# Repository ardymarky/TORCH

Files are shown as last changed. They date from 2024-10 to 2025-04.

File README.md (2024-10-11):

# TORCH
Code and Solidworks

To clone github, go to a folder or directory of your choice and run 
'git clone https://github.com/ardymarky/TORCH.git Torch`

To push you changes to the github, run these commands in order:

`git pull`
`git status` (make sure everything looks good)
`git add . ` (adds your changes)
`git commit -m "your message here"` (bundles them to a commit with a message)
`git push`  (push your changes to the main github branch!)

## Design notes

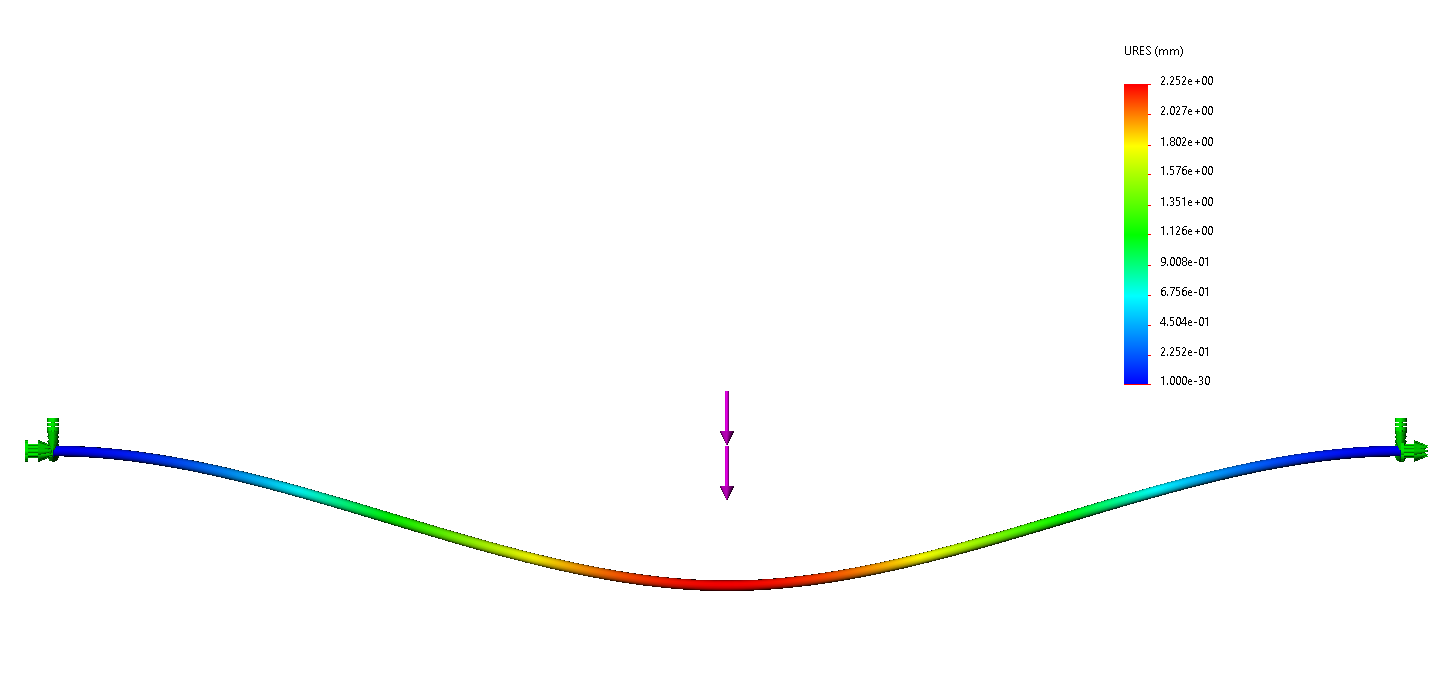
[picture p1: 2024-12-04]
6061_Aluminum_Alloy_Max_Deflection.png

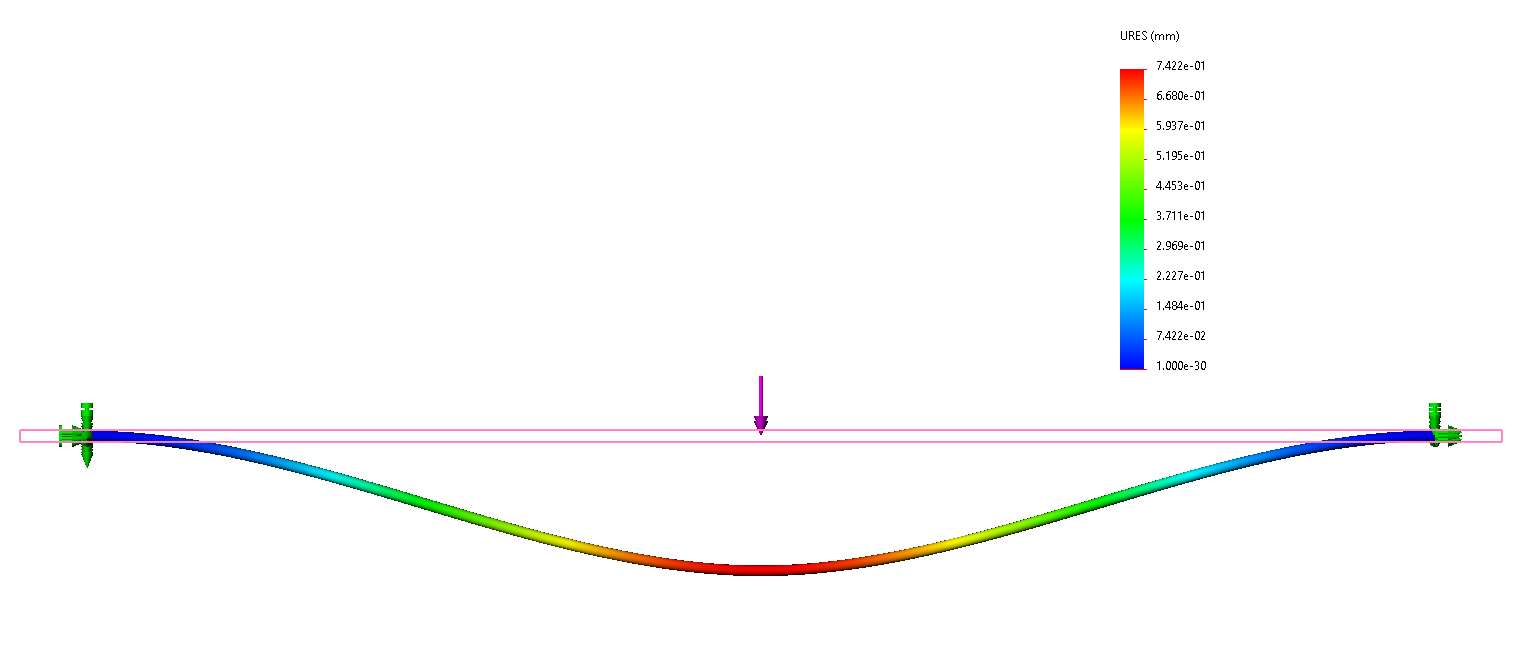
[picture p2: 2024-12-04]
Carbon_Steel_Max_Deflection.png

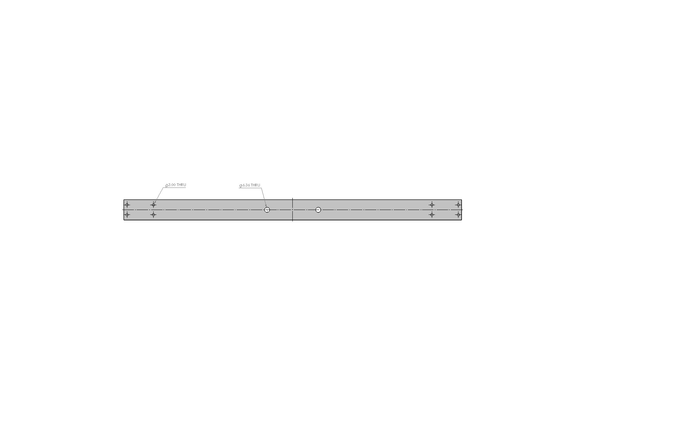
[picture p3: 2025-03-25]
solidworks/1630T291_Multipurpose 6061 Aluminum U-Channel_hole_cuts.JPG

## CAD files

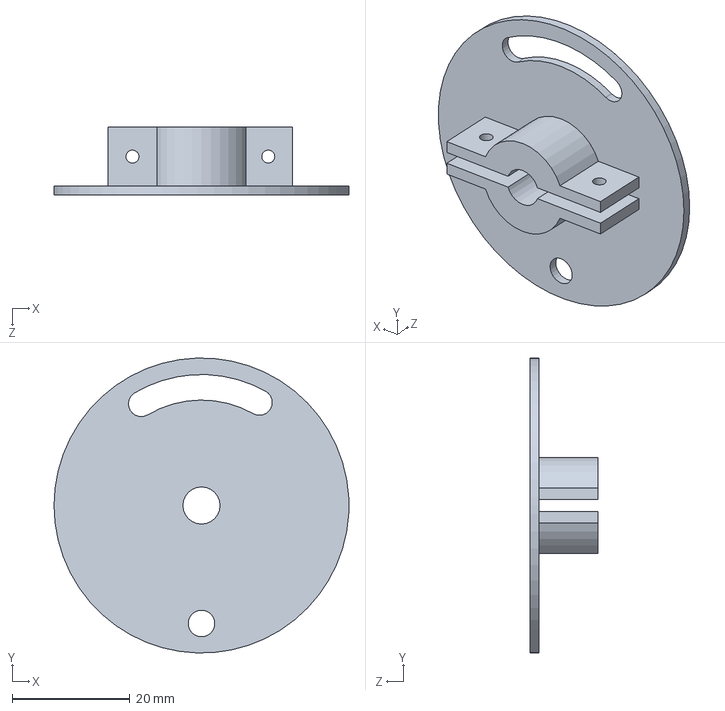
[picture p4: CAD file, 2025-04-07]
solidworks/WheelKey.SLDPRT
50.0 x 50.0 x 11.5 mm

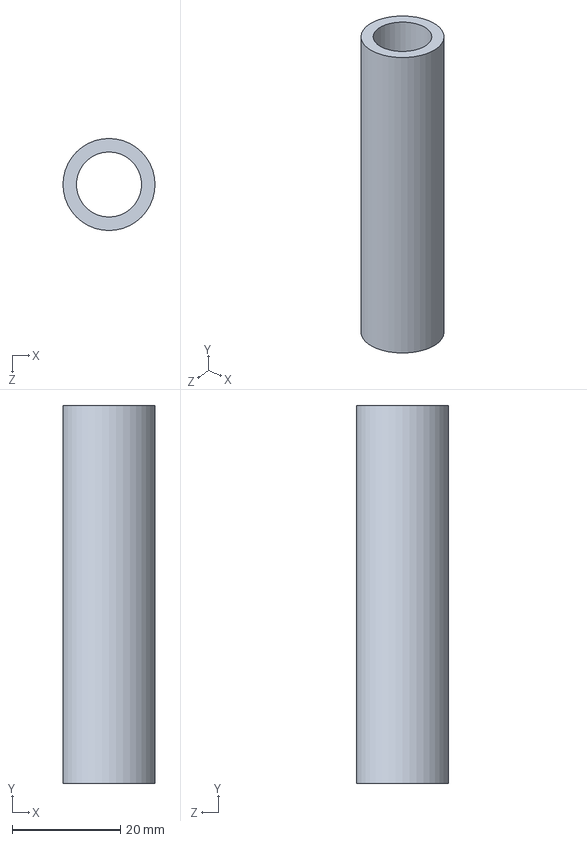
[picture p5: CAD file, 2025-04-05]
solidworks/rubberextrusion.SLDPRT
17.0 x 70.0 x 17.0 mm

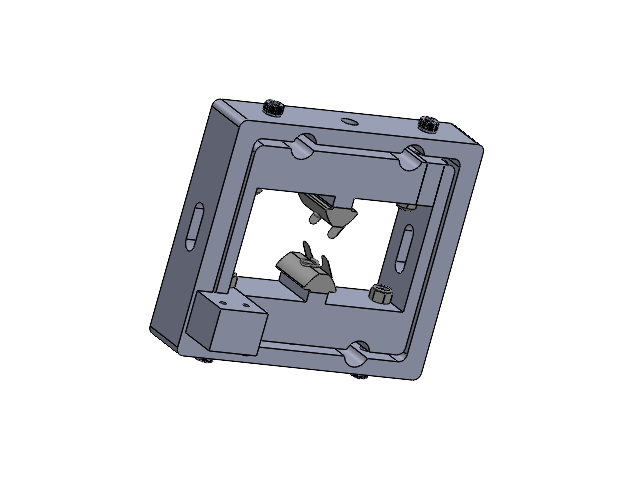
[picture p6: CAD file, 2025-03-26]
solidworks/Linear_rail_hold_V4_8.SLDASM
Linear_rail_hold_V4_2_new
Linear_rail_hold_V4_new
Linear_rail_hold_V4
91290A172_Alloy Steel Socket Head Screw x 4
5278N23_T-Slotted Framing Fasteners x 2
94645A101_High-Strength Steel Nylon-Insert Locknut x 4

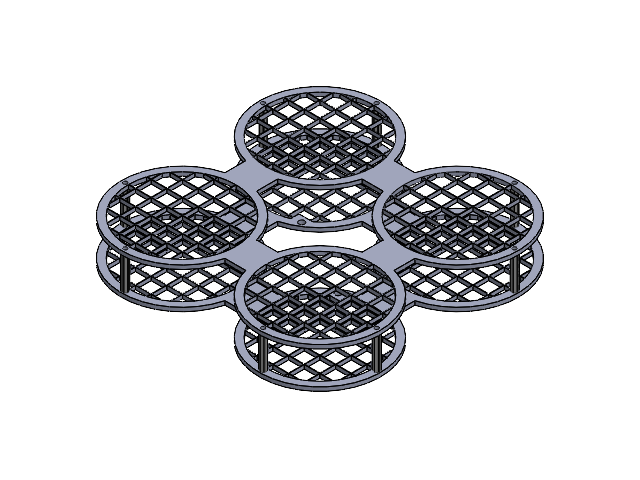
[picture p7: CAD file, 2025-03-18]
solidworks/drone_guard_combo.SLDASM
guard_bottom1_combo
93655A360_Male-Female Threaded Hex Standoff x 8
guard_combo

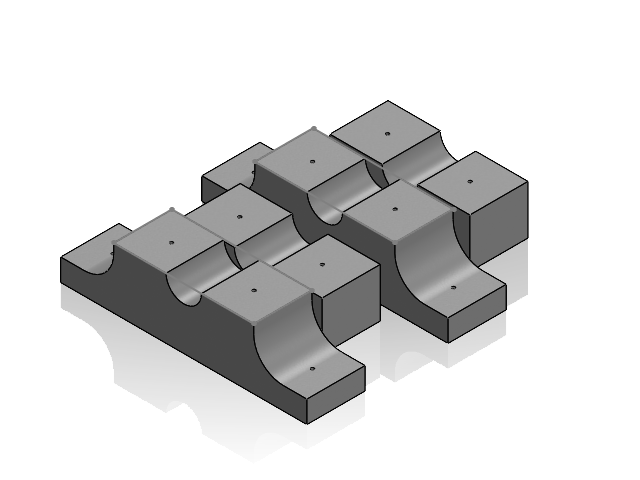
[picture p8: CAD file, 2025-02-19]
solidworks/clampPrint.SLDASM
clampBottomPrint x 2
clampTopPrint x 2

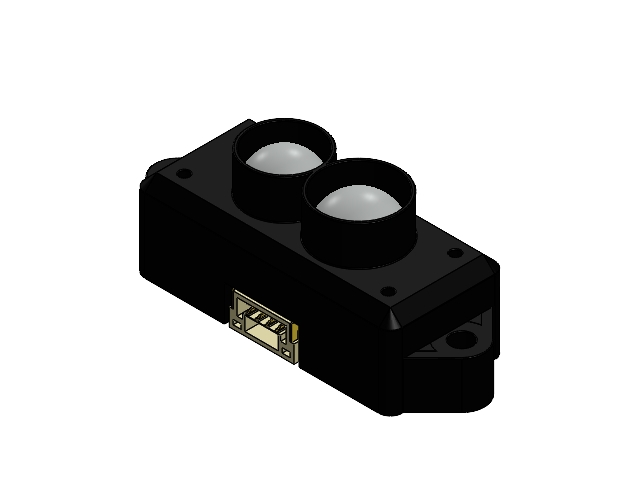
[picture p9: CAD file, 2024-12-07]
solidworks/LiDAR Benewake TFMini.SLDASM
LiDAR Benewake TFMini_1.stp
Lente Grande.stp
Lente Pequena.stp
SM04B-GHS-TB.stp
Chipset.stp
Adesivo.stp

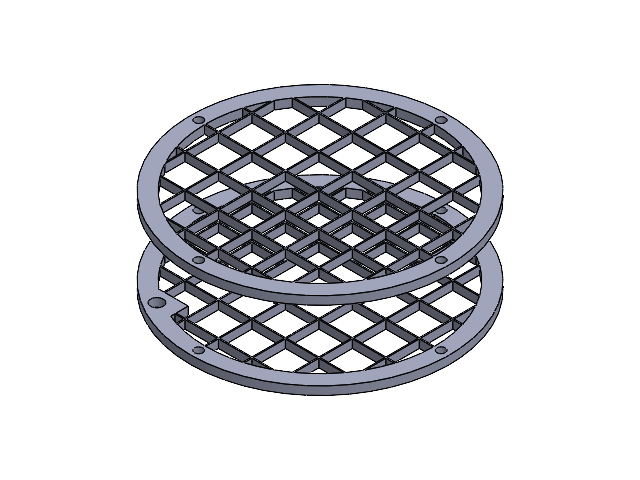
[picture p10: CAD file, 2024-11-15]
solidworks/one quard.SLDASM
guard
guard_bottom1

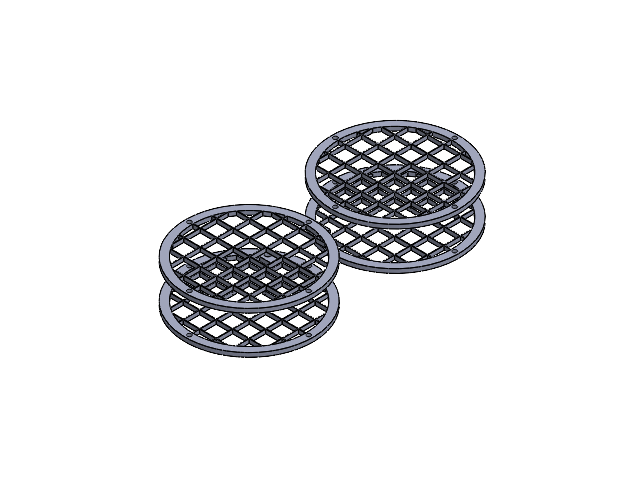
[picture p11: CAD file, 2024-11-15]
solidworks/half prop.SLDASM
guard x 2
guard_bottom1 x 2

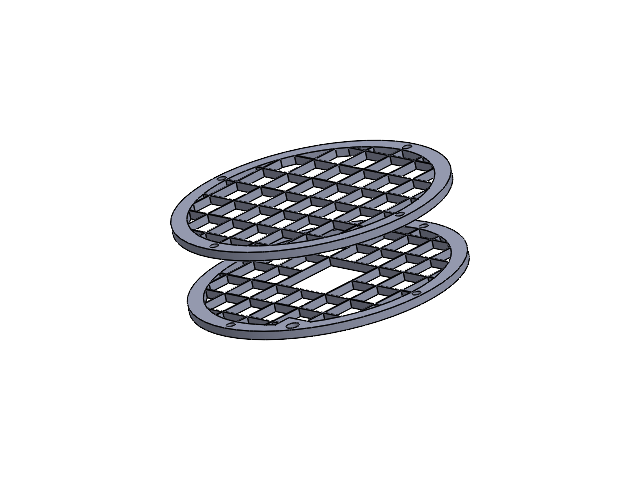
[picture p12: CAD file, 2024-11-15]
solidworks/one quard_1.SLDASM
guard
guard_bottom1

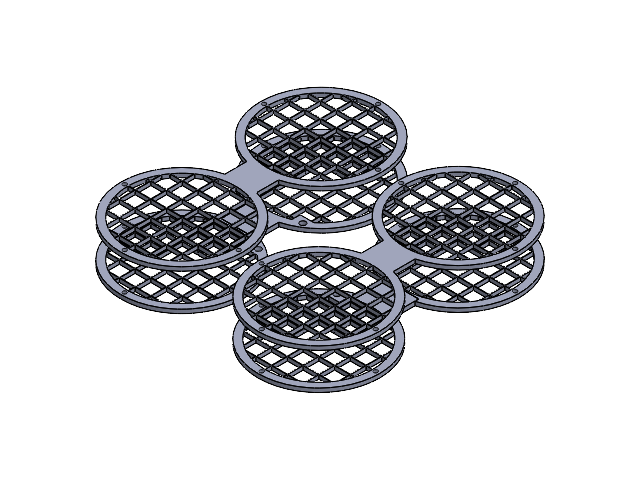
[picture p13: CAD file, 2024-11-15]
solidworks/experiment.SLDASM
half prop_COMBOpart x 2

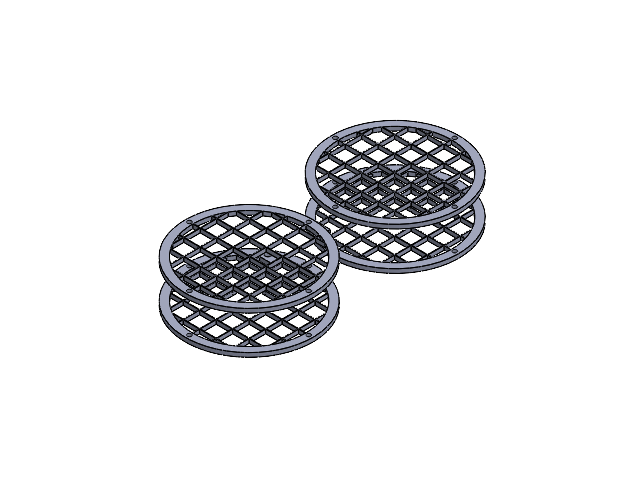
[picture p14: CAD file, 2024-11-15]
solidworks/half prop_COMBO.SLDASM
guard x 2
guard_bottom1 x 2

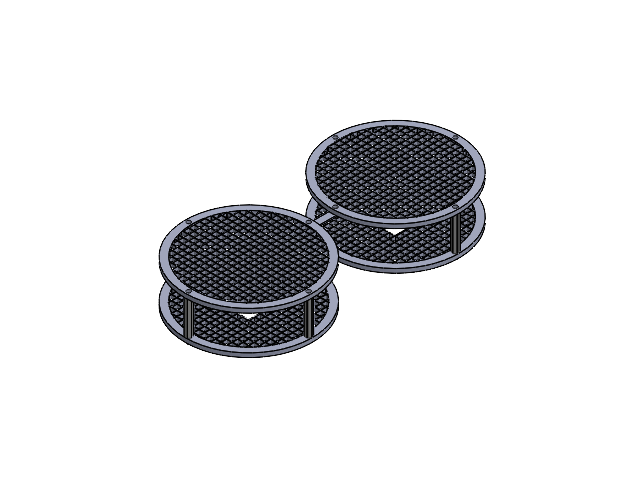
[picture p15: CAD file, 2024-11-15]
solidworks/half prop_one.SLDASM
guard x 2
93655A360_Male-Female Threaded Hex Standoff (1) x 6
guard_bottom1 x 2
connector x 2

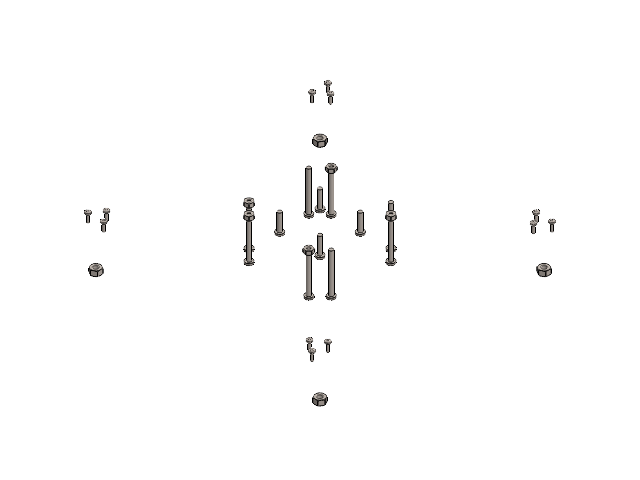
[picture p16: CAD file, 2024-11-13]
solidworks/final assembly.SLDASM
pan cross head_am x 24
hex nut style 2_am x 9

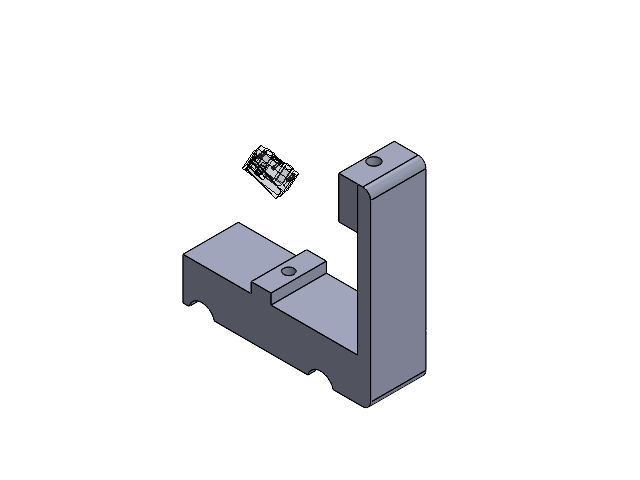
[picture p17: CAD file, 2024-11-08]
solidworks/Assem1.SLDASM
Linear_rail_hold_V4
Bottom.STEP
Top.STEP
Pins.STEP x 3
Button.STEP
Lever.STEP

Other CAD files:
solidworks/innerrail.SLDASM
solidworks/Linear_rail_hold_V4_3.SLDPRT.SLDASM
solidworks/E-Stop With Housing.SLDASM
solidworks/1630T116_Multipurpose 6061 Aluminum U-Channel.SLDPRT
solidworks/1630T291_Multipurpose 6061 Aluminum U-Channel Counterweight rack.SLDPRT
solidworks/1630T291_Multipurpose 6061 Aluminum U-Channel.SLDPRT
solidworks/1630T291_Multipurpose 6061 Aluminum U-Channel_hole_cuts.DWG
solidworks/1630T291_Multipurpose 6061 Aluminum U-Channel_hole_cuts.SLDDRW
solidworks/1630T332_Multipurpose 6061 Aluminum U-Channel.SLDPRT
solidworks/1865K36_Aluminum Easy-Access Base-Mounted Shaft Support.SLDPRT
solidworks/1865K36_Aluminum Easy-Access Base-Mounted Shaft Support1.SLDPRT
solidworks/2435K1_Idler Rotary Shaft.SLDPRT
solidworks/3014T45_Steel Eyebolt with Shoulder - for Lifting (1).SLDPRT
solidworks/3018T14_Galvanized Steel Eyebolt with Nut and with Shoulder (1).SLDPRT
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

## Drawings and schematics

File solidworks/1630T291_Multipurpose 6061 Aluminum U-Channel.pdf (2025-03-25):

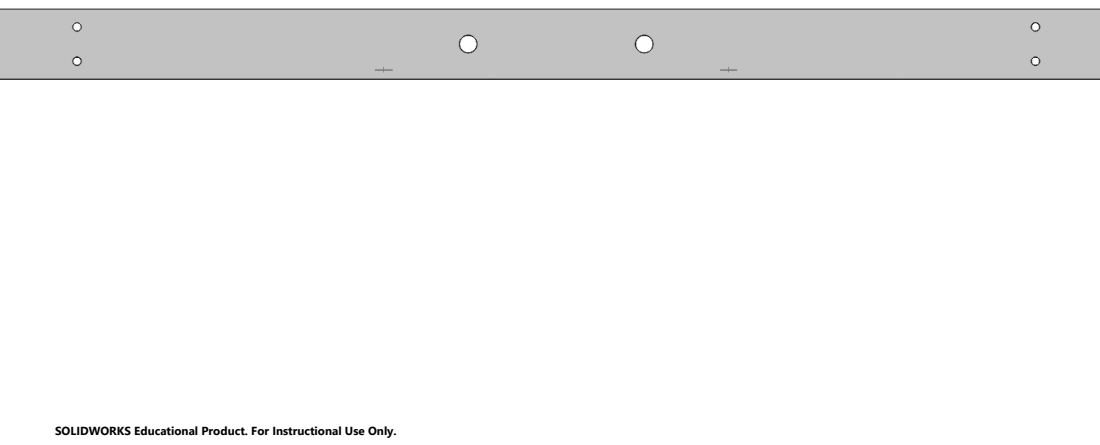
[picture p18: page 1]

SOLIDWORKS Educational Product. For Instructional Use Only.

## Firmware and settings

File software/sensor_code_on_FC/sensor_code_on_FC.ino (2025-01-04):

typedef union WheelReading{
  float angle_uart;
  byte byteArray[4]; /* you can use other variable types if you want. Like: a 32bit integer if you have 4 8bit variables in your struct */
};

uint8_t WE_state = 0;
WheelReading wheel_reading;

void setup() {
  Serial.begin(9600);
  Serial2.begin(9600);
  Serial3.begin(115200);
}

void loop() {
  if (Serial2.available()) {
    readWE_data();
  }
  if (Serial3.available()) {
    readRF_data();
  }
}

void readWE_data() {

    uint8_t WE_state = 0;
    uint8_t byte_num = 0;

    while (1) {

      if (Serial2.available()) {

        uint8_t val_1 = Serial2.read();

        if (WE_state == 2 && byte_num < 4) {
          wheel_reading.byteArray[byte_num] = val_1;
          byte_num += 1;
        }
        else if (WE_state == 2 && byte_num >= 4) {
          WE_state = 0;
          byte_num = 0;
          break;
        }
        else if (val_1 == 0x69 && WE_state == 0) {
          WE_state = 1;
          
        }
        else if (val_1 == 0x69 && WE_state == 1) {
          WE_state = 2;
        }
        else {
          WE_state = 0;
        }      
      }
    }

    unsigned long curMillis = millis();
    // Serial.print("Wheel reading: "); 
    Serial.print(wheel_reading.angle_uart);
    Serial.print("\t");
    Serial.println(curMillis);
}


void readRF_data() {
  int frame_size = 7;

    uint8_t frame[frame_size];
    uint8_t lastChar = 0x00; 

    while (1) {

      if (Serial3.available()) {      
        uint8_t curChar = Serial3.read();

        if ((lastChar == 0x59) && (curChar == 0x59)) {
          // Break to begin frame
          break;
          
        } else {
          // We have not seen two 0x59's in a row -- store the current character and continue reading.         
          lastChar = curChar;
        }           
      }
    }

    uint8_t checksum = 0x59 + 0x59;
    for (int i=0; i<frame_size; i++) {
      // Read one character
      while (!Serial3.available()) {
        // wait for a character to become available
      }    
      frame[i] = Serial3.read();

      // Store running checksum
      if (i < frame_size-2) {
        checksum += frame[i];
      }
    }

    // Step 3: Interpret frame
    uint16_t dist = (frame[1] << 8) + frame[0];
    uint16_t st = (frame[3] << 8) + frame[2];
    uint8_t reserved = frame[4];
    uint8_t originalSignalQuality = frame[5];


    // Step 4: Store values
    int distance = dist;
    int strength = st;

    unsigned long curMillis = millis();
    Serial.print("Rangfinder:");
    Serial.print("\t");
    Serial.print(distance);
    Serial.print(" cm\t");
    // Serial.print(strength);
    // Serial.print("\t");
    Serial.println(curMillis);
}

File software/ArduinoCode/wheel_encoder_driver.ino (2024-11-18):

#include "SPI.h"

#include "MLX90316.h"

/* MLX90316 Rotary Position Sensor */
byte pinSS = 3;
byte pinSCK = 4;
byte pinMOSI = 5;
// float rough_gain= 0x8;
float angle;

//Metro mlxMetro = Metro(5); 
MLX90316 mlx_1 = MLX90316(); 

void setup(){
  Serial.begin(9600); 
  mlx_1.attach(pinSS,pinSCK,pinMOSI); 
  SPI.begin();
  // Serial.println("MLX90316 Rotary Position Sensor");
}

void loop() {
  
    angle = mlx_1.readAngle();
    // float rough_gain = SPI.transfer(0x8);
    // Serial.print("angle = ");Serial.println((float)angle/10);

    typedef union WheelReading{
      float angle_uart;
      byte byteArray[4]; /* you can use other variable types if you want. Like: a 32bit integer if you have 4 8bit variables in your struct */
    };

    WheelReading wheel_reading;

    wheel_reading.angle_uart = (float)angle/10;

    Serial.write(0x69);
    Serial.write(0x69);
    Serial.write(wheel_reading.byteArray[0]);
    Serial.write(wheel_reading.byteArray[1]);
    Serial.write(wheel_reading.byteArray[2]);
    Serial.write(wheel_reading.byteArray[3]);

    }
  

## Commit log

2024-10-11 solidworks files
    [1865K36_Aluminum Easy-Access Base-Mounted Shaft Support.SLDPRT, 2435K1_Idler Rotary Shaft.SLDPRT, 4063N11_Base-Mounted Dual Shaft Support.SLDPRT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]
2024-10-11 Added Wheel Encoder Mount with proper sizing and end u channel beams
    [4143N13_Rotary Shaft.SLDPRT, Rod_mount.SLDPRT]
2024-10-11 zac follow up push
    [1630T116_Multipurpose 6061 Aluminum U-Channel.SLDPRT, 1630T291_Multipurpose 6061 Aluminum U-Channel.SLDPRT, Wheel_encoder_mount.SLDPRT]
2024-10-14 drone mounts finished
    [92595A205_Iron Wing-Head Thumb Screw.SLDPRT, Rod_mount.SLDPRT, WheelKey.SLDPRT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]
2024-10-16 power adapter, quadbase tube
    [5548K87_Hard Nylon Plastic Tubing for Air and Water.SLDPRT, Micro Limit Switch.STEP, QuadBase.SLDPRT]
2024-10-18 Added acryllic saftey Shield with mounting bars
    [8020-40-4040 X 150.SLDPRT, 8560K264_Clear Scratch- and UV-Resistant Cast Acrylic Sheet.SLDPRT, 8560K264_Clear Scratch- and UV-Resistant Cast Acrylic Sheet_TOP_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]
2024-10-19 Added counter weights with E-stop buttom. Removed Eyebolts plates. There was something wrong with the geometery when I tried to mate to it and would corrupt the file
    [6544K811_Low-Carbon Steel Sheet.SLDPRT, 6775T111_Low-Carbon Steel Bar.SLDPRT, 6775T121_Low-Carbon Steel Bar.SLDPRT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]
2024-10-22 Added Wire rope for pulley to the parts list. Not included in assmebley. Added endcaps to assembly.
    [34235T654_Low-Stretch Coated Wire Rope-Not for Lifting.SLDPRT, 40 end cap.SLDPRT, 8982K885_Multipurpose 6061 Aluminum 90 Degree Angle.SLDPRT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]
2024-10-23 Added Mates to constraint linear rail mounts
    [J115F11C12VDCSH.9--3DModel-STEP-56544 (1).STEP, Micro Limit Switch.SLDASM]
2024-10-24 added rangefinder data and scripts
    [RangeFinderData.xlsx]
2024-10-24 added rubber feet and tried to organize the files a bit
    [RubberFeet.SLDPRT]
2024-10-24 added wiring cables
    [8005N11_T-Slotted Framing Cable Holder.SLDPRT, J115F11C12VDCSH.9--3DModel-STEP-56544 (1).STEP, J115F11C12VDCSH.9--3DModel-STEP-56544.STEP]
2024-11-08 Added Wheel Encoder Block and relocated Emergency Stop Button
    [8560K264_Clear Scratch- and UV-Resistant Cast Acrylic Sheet.SLDPRT, 8983K211_Multipurpose 304 Stainless Steel Sheet.SLDPRT, 92949A540_18-8 Stainless Steel Butt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]
2024-11-13 Resized to 3 in Quadcopter
    [BL_touch_Limit_plate.SLDPRT, BL_touch_Limit_plate.STL, QuadBase.SLDPRT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]
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2024-11-27 some updates
    [Linear_rail_hold_V4.SLDPRT, drone_guard_combo.SLDASM, guard_bottom1_combo.SLDPRT]
2024-12-03 AC connector bracket
    [8983K211_Multipurpose 304 Stainless Steel Sheet_Power Connector.SLDPRT, BL_touch_Limit_plate.SLDPRT, BL_touch_Limit_plate.STL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]
2024-12-06 Added AC DC Box Mounting plate (Top and Bottom) and Relay PDB and mounted.
    [AC_DC_Converter_Mount.SLDPRT, AC_DC_TOP_PLATE.SLDPRT, AC_DC_TOP_PLATE_STANDOFF.SLDPRT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]
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2025-01-04 fixed some bugs on tfmini and wrote ercf driver in c++. have not tested yet through spaaro
    [MLX90316.cpp, wheel_encoder_driver.ino]
2025-01-06 Static and Frequency tests
    [6112K54_Linear Motion Shaft.SLDPRT, QuadBase.SLDPRT]
2025-01-28 endstop weight reduction
    [endstop_2point0.SLDPRT, endstop_2point0_1.SLDPRT]
2025-01-30 bolt correction
    [Linear_rail_hold_V4.SLDPRT, Linear_rail_hold_V4_2.SLDPRT, Linear_rail_hold_V4_2_new.SLDPRT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]
2025-02-06 xdirection holds
    [Shaft support SK12.SLDPRT, tpu_piece.SLDPRT, xlinearrailmount.SLDPRT]
2025-02-18 Updated drone frame for motor cutouts
    [QuadBase.SLDPRT, drone_guard_combo.SLDASM, guard_bottom1_combo.SLDPRT]
2025-02-18 Updated guard combo (bottom) to attach arduino mini via zip ties. Will add mRo mini telem module once dimensions are confirmed
    [drone_guard_combo.SLDASM, guard_bottom1_combo.SLDPRT]
2025-02-19 Created test rotory shaft clamps to use until alu clamps come in. Will have to drill holes (did this so we could use screws that we had...
    [clampBottomPrint.SLDPRT, clampPrint.3MF, clampPrint.SLDASM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]
2025-02-19 Added new frame compatible with test clamps
    [quadBasePrintedClamps.3MF, quadBasePrintedClamps.SLDPRT]
2025-02-19 Made drill holes more visable for clamps
    [clampBottomPrint.SLDPRT, clampPrint.3MF, clampPrint.SLDASM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]
2025-02-19 Guide holes too narrow, had to make larger for prints
    [clampBottomPrint.SLDPRT, clampPrint.3MF, clampPrint.SLDASM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]
2025-02-27 lidar mount
    [Wheel_encoder_mount_v2_alteration.SLDPRT, Wheel_encoder_mount_v2_alteration_thickness.SLDPRT]
2025-03-06 Re-modeled counter-weight racks and cable placement
    [1630T291_Multipurpose 6061 Aluminum U-Channel Counterweight rack.SLDPRT, 1630T291_Multipurpose 6061 Aluminum U-Channel.SLDPRT, 1630T332_Multipurpose 6061 Alumi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]
2025-03-06 CARBON ROD
    [Rod_mount.SLDPRT, Wheel_encoder_mount_v2_alteration.SLDPRT, tpu_piece_rod.SLDPRT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]
2025-03-18 horizontal rail holds
    [drone_guard_combo.SLDASM, endstop_lidar.SLDPRT, guard_bottom1_combo.SLDPRT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]
2025-03-18 Addind updated TPU parts, Wheel Encoder Mounts, Endstop Lidar, and Rod Mounnt for carbon rod
    [AC_DC_Converter_Mount.STL, AC_DC_TOP_PLATE.STL, Relay_cover.STL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]
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2025-03-24 updated wheel key swath and pulley diameter
    [TORCH_PULLEY_WHEEL.SLDPRT, WheelKey.SLDPRT]
2025-03-24 edited the rod mounts to accomodate new bearing
    [Rod_mount_carbon_rod.SLDPRT, Rod_mount_two holes.SLDPRT, Wheel_encoder_mount_carbon_rod_V2.SLDPRT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]
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2025-03-25 Updated counterweight rack to reflect new changes and added all eyebolts
    [1630T291_Multipurpose 6061 Aluminum U-Channel Counterweight rack.SLDPRT, 1630T291_Multipurpose 6061 Aluminum U-Channel.SLDPRT, 1630T291_Multipurpose 6061 Alumi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]
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2025-03-26 drone wire route thickness
    [dronewiring.SLDPRT]
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2025-04-03 discard extrusion on endstop
    [endstop_lidar.SLDPRT]
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
